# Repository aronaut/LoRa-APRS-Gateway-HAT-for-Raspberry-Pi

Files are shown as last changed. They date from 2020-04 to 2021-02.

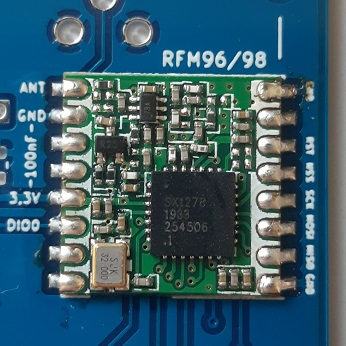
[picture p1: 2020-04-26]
Pictures/LoRa_APRS_3.jpg

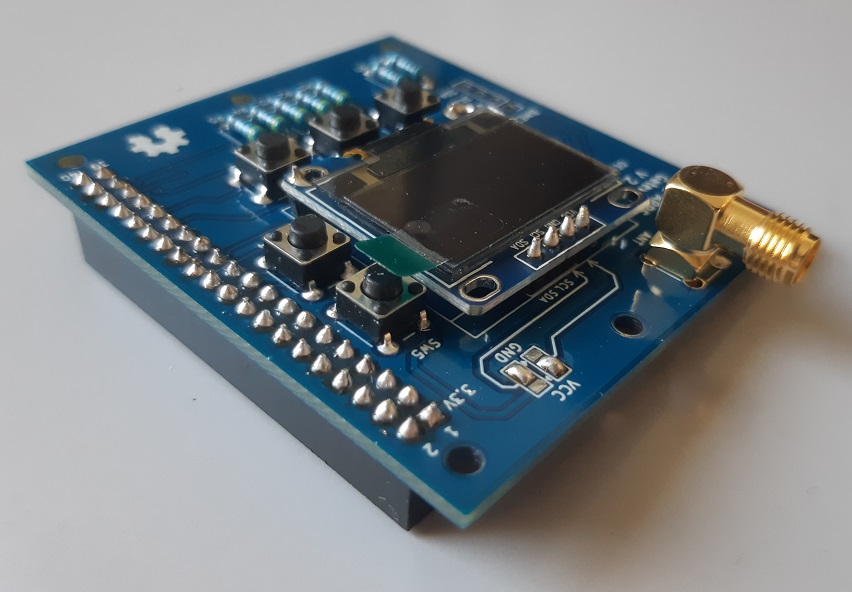
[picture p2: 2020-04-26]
Pictures/LoRa_APRS_7.jpg

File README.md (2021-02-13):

What is it?
-----------
With this LoRa APRS board you can build a LoRa APRS single channel Gateway.  
The Board is based on the development of https://www.lora-aprs.at/ and http://www.iot4pi.com/  
It works with a Raspberry Pi (2 Model B, 3 Model B an B+, Zero WH).  
Power is provided by Raspberry Pi.

What you find here
------------------
- KiCad Fils
- Gerber Files
- Manuals
- Pictures of the LoRa-APRS-Board

Info & Software
---------------
You find information and Software for the LoRa-APRS Gateway at  
https://www.aronaut.at/2019/11/lora-aprs-gateway-fur-raspberry-pi/  
https://www.lora-aprs.at/  
http://www.iot4pi.com/de/hardware/lora-gateway/  
https://github.com/tomelec/RPi-LoRa-KISS-TNC

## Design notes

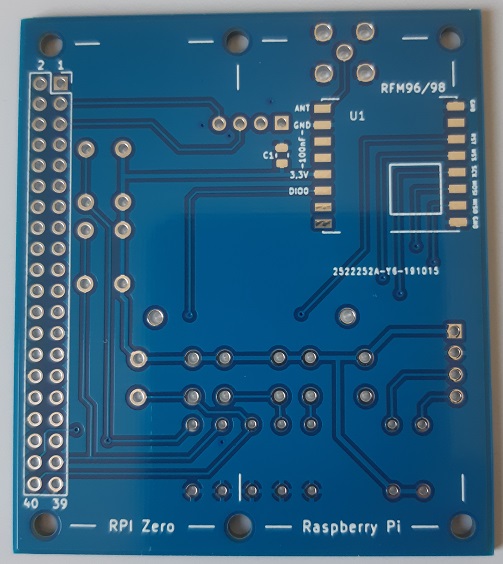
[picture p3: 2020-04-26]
Pictures/LoRa_APRS_2.jpg

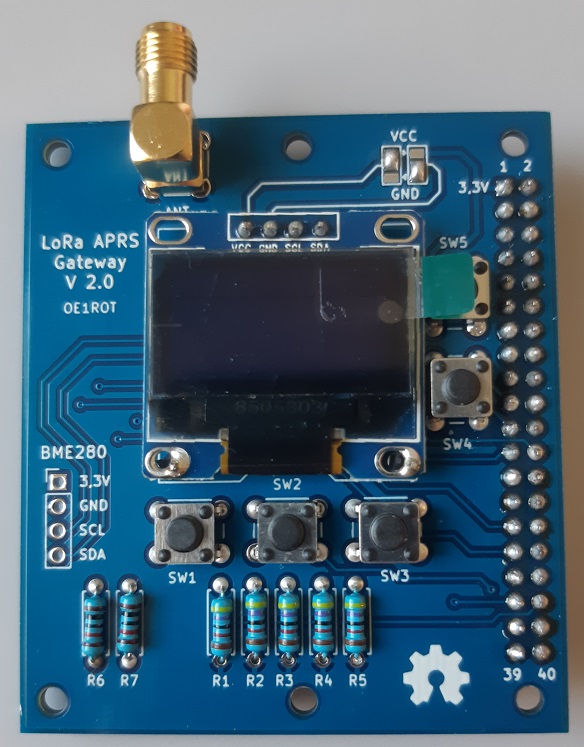
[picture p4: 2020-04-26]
Pictures/LoRa_APRS_5.jpg

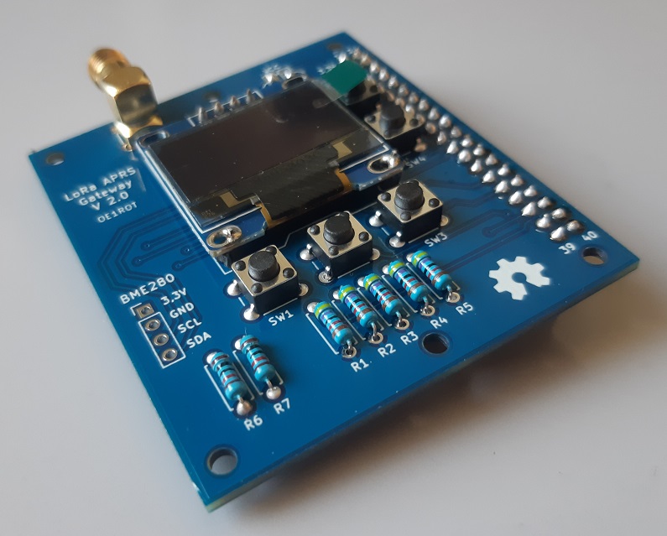
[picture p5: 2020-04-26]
Pictures/LoRa_APRS_6.jpg

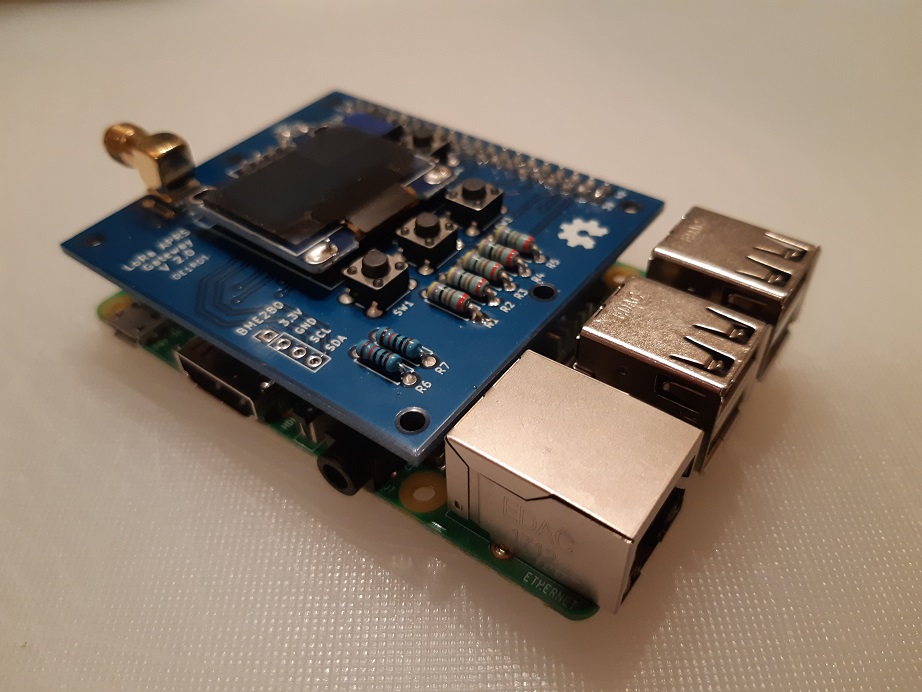
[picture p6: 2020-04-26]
Pictures/LoRa_APRS_8.jpg

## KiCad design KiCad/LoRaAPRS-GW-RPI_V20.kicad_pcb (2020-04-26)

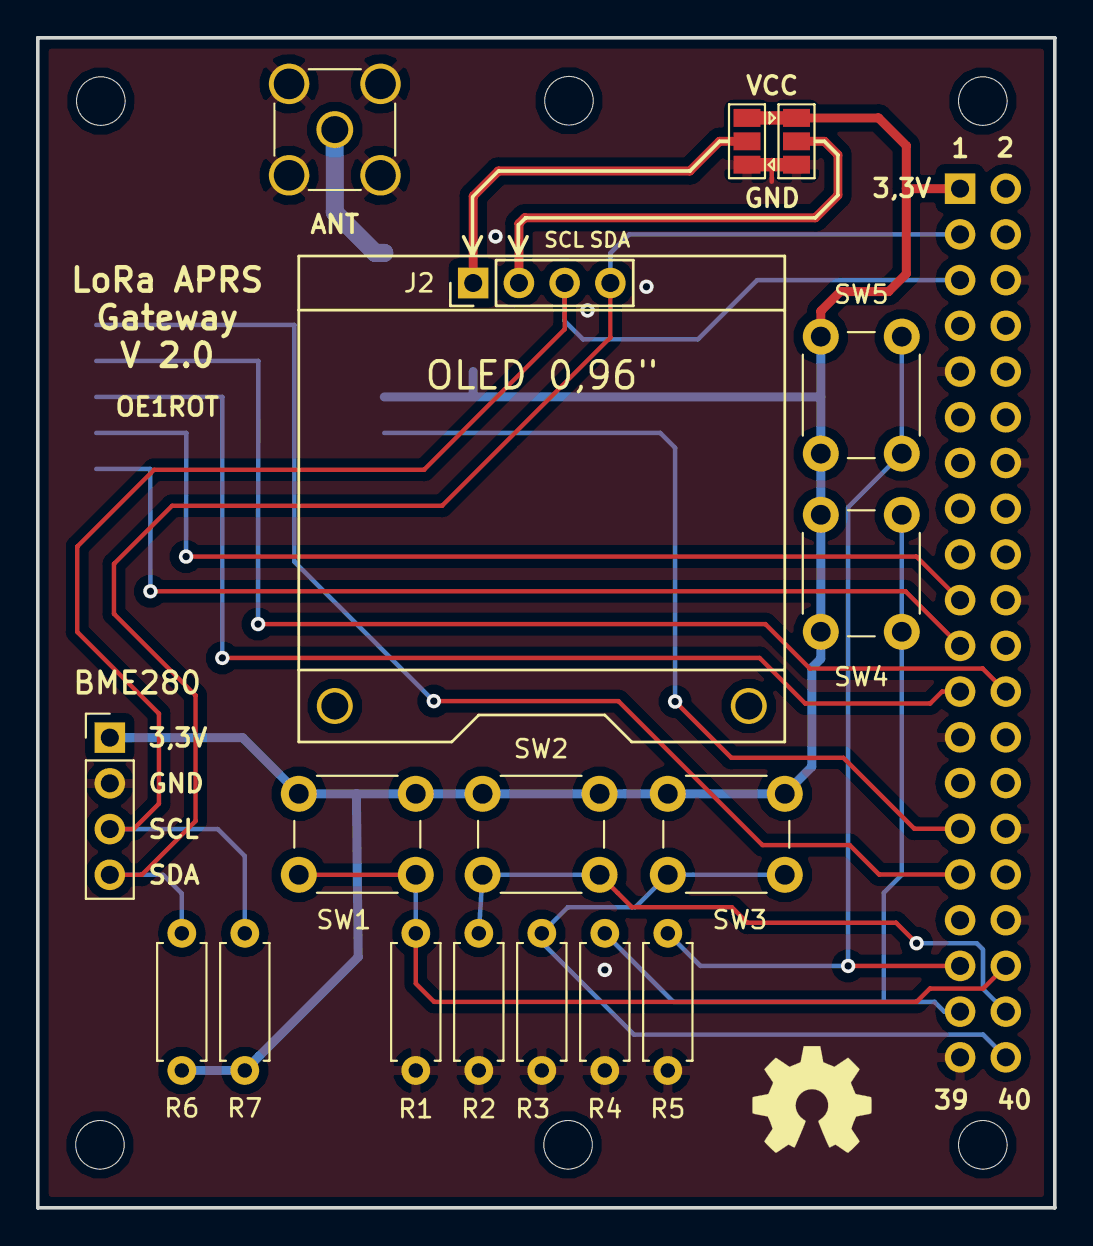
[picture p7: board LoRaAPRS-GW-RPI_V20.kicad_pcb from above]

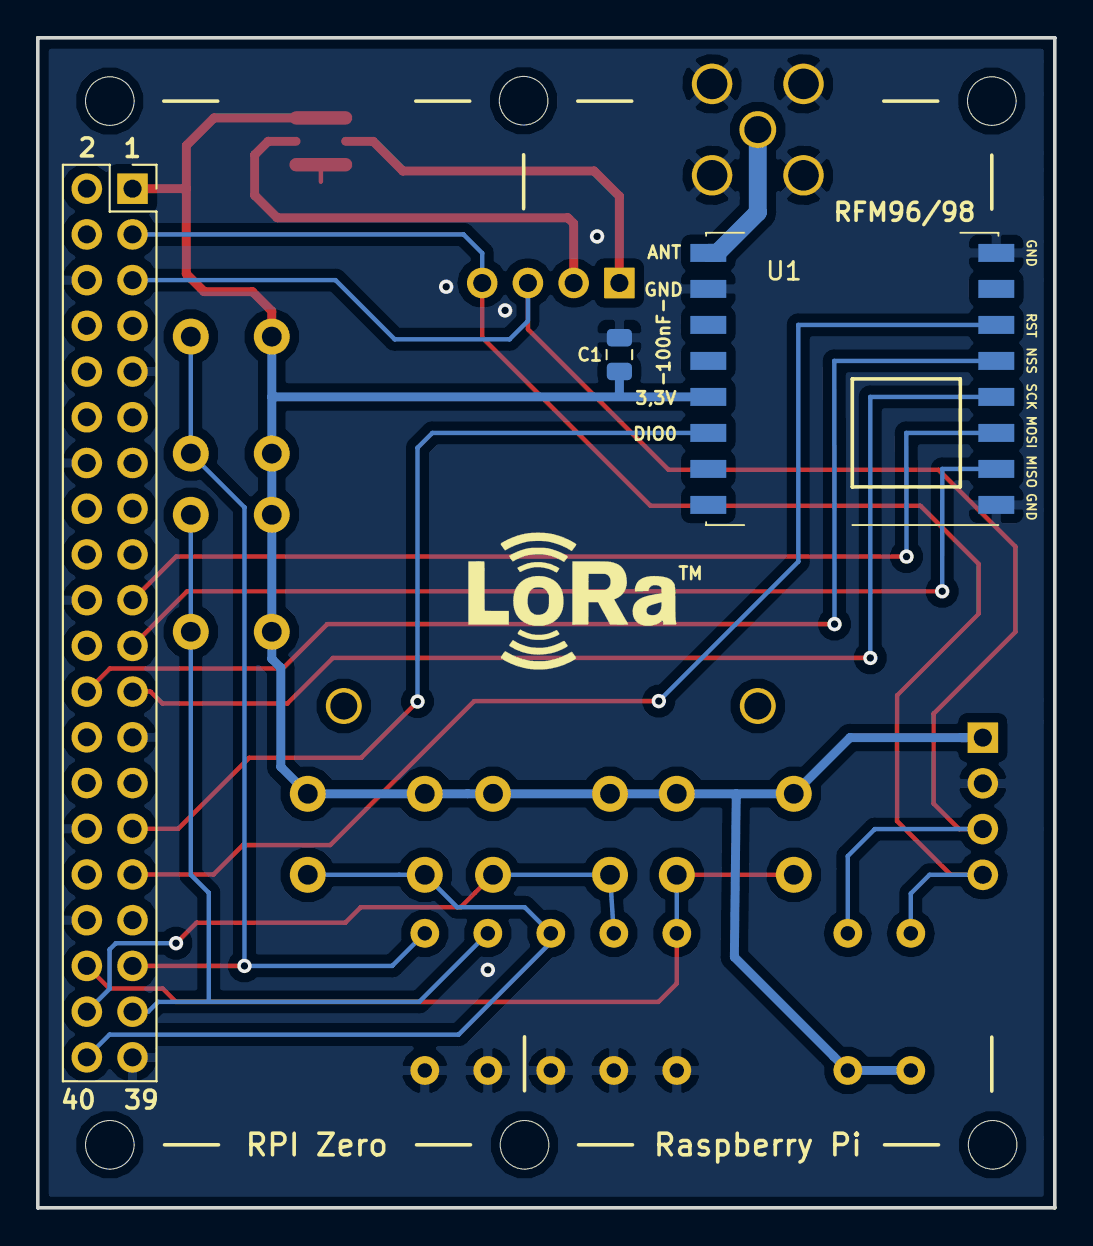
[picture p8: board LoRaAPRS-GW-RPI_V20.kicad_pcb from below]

Board: 2 copper layers, 56.5 x 65.0 mm, 20 parts (3 on the bottom side), 18 nets.

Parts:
AE1: Antenna_Shield; SMA_Amphenol_901-144_Vertical
C1: C; C_0805_2012Metric
J1: Raspberry PI Header; PinSocket_2x20_P2.54mm_Vertical
J2: Display; OLED_0,96_II
J3: BME280; PinHeader_1x04_P2.54mm_Vertical
JP1, JP2: SolderJumper_3_Open; SolderJumper-3_P1.3mm_Open_Pad1.0x1.5mm
R1, R2, R3, R4, R5: 47k; R_Axial_DIN0207_L6.3mm_D2.5mm_P7.62mm_Horizontal
R6, R7: 10k; R_Axial_DIN0207_L6.3mm_D2.5mm_P7.62mm_Horizontal
SW1, SW2, SW3, SW4, SW5: SW_Push; SW_PUSH_6mm_H5mm
U1: RFM96W-433S2; HOPERF_RFM9XW_SMD

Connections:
+3V3: C1.1, J1.1, J3.1, JP1.3, JP2.1, R6.1, R7.1, SW1.1, SW2.1, SW3.1, SW4.1, SW5.1, U1.13
D1: J2.1, JP1.2
D2: J2.2, JP2.2
DIO0: J1.29, U1.14
DOWN: J1.37, R4.1, SW4.2
GND: AE1.2, C1.2, J1.6, J1.9, J1.14, J1.20, J1.25, J1.30, J1.34, J1.39, J3.2, JP1.1, JP2.3, R1.2, R2.2, R3.2, R4.2, R5.2, U1.1, U1.8, U1.10
MISO: J1.21, U1.2
MOSI: J1.19, U1.3
NSS: J1.24, U1.5
unnamed: AE1.1, U1.9
Reset: J1.31, U1.6
SCK: J1.23, U1.4
SCL: J1.5, J2.3, J3.3, R7.2
SDA: J1.3, J2.4, J3.4, R6.2
T1: J1.36, R1.1, SW1.2
T2: J1.38, R2.1, SW2.2
T3: J1.40, R3.1, SW3.2
UP: J1.35, R5.1, SW5.2

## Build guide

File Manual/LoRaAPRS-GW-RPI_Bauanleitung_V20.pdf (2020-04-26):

# LoRa-APRS Gateway HAT V2.0 - Bauanleitung

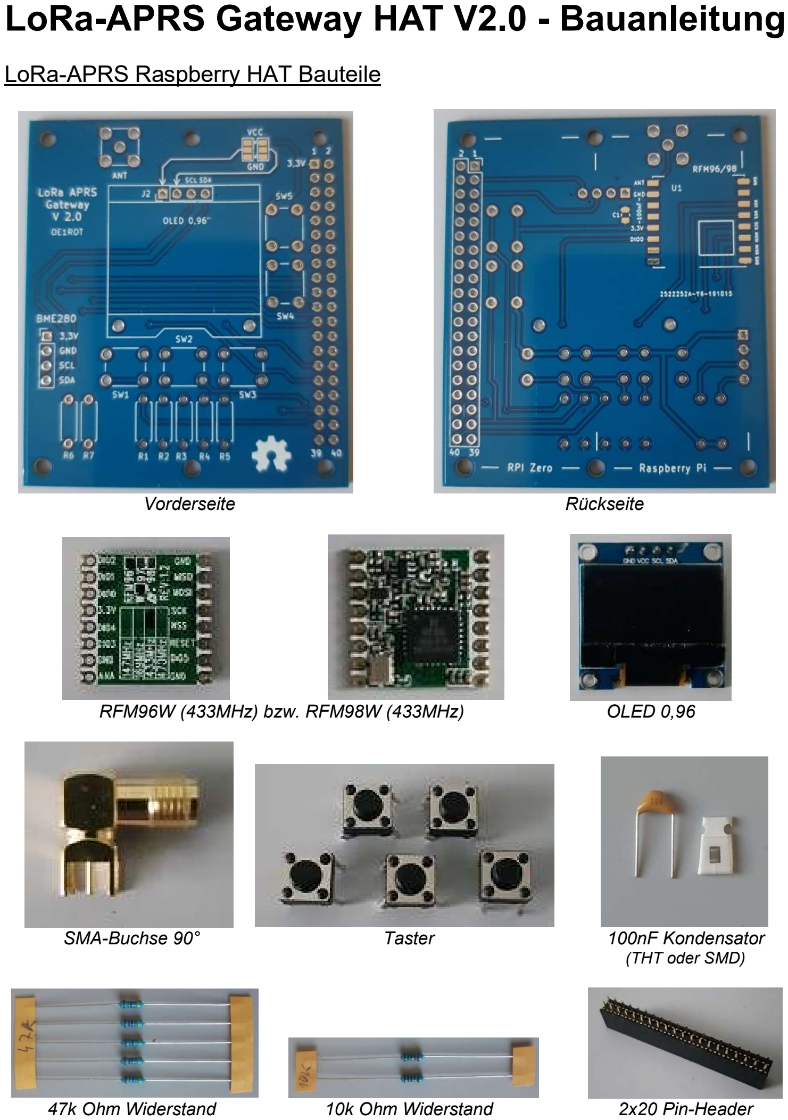
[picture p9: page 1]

LoRa-APRS Raspberry HAT Bauteile

Vorderseite | Rückseite
RFM96W (433MHz) bzw. RFM98W (433MHz) | OLED 0,96
SMA-Buchse 90° | Taster | 100nF Kondensator (THT oder SMD)
47k Ohm Widerstand | 10k Ohm Widerstand | 2x20 Pin-Header

### 1. Schritt – RFM96W / RFM98W

Als ersten Schritt wird der RFM96W/98W angelötet. Am einfachsten ist es das Lötzinn auf ein Pad (z.B. in einer Ecke) für den RFM96W/98W aufzutragen und danach den Baustein auszurichten. Ist der RFM-Chip ausgerichtet kann mit dem Lötkolben das Pad erwärmt werden und mit ein wenig Druck wird dieser fixiert. Dann werden die restlichen Pads an die Platine angelötet. Ein Fluxstift oder Lötpaste erleichtert das Aufbringen des Lötzinns.
Zur Kontrolle können die Lötpunkte mit einem Durchgangsprüfer kontrolliert werden.

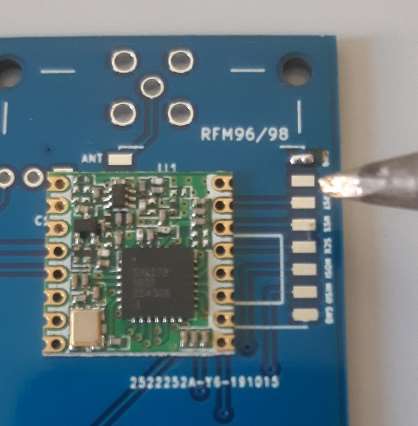
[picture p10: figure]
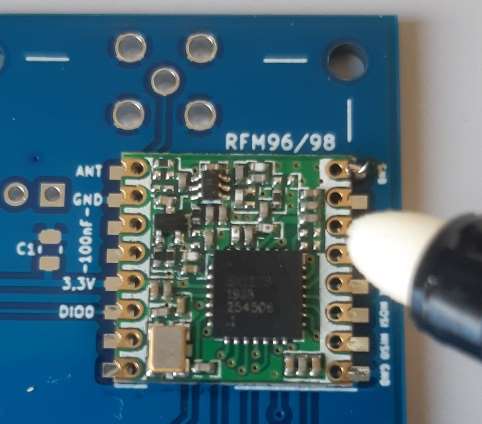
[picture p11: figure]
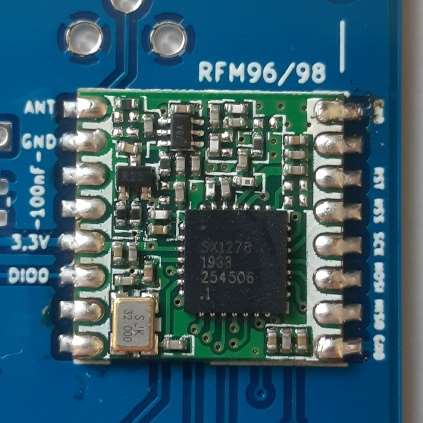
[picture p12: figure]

Lötzinn auftragen | RFM96W/98W ausrichten | RFM96W/98W anlöten
| Fluxstift

Passende Tranceiver Chip:
-) HopeRF: RFM96W / RFM98W (based on Semtech SX1279 / SX1278)

### 2. Schritt – Kondensator

Der 100nF Kondensator wird nun neben dem RFM96/98 angelötet.
Entweder man lötet einen THT Kondensator zwischen den RFM Pins GND-3,3V oder man lötet einen SMD Kondensator (Größe: 0805) an die vorhergesehenen Pads.

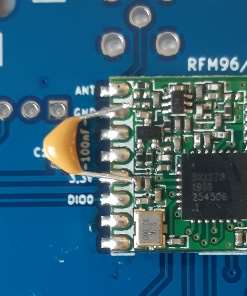
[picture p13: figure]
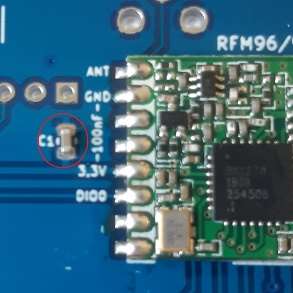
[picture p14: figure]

THT Kondensator | oder | SMD Kondensator

### 3. Schritt - Widerstände und Taster

Die Widerstände und die Taster werden nun an den vorhergesehenen Stellen eingelötet.

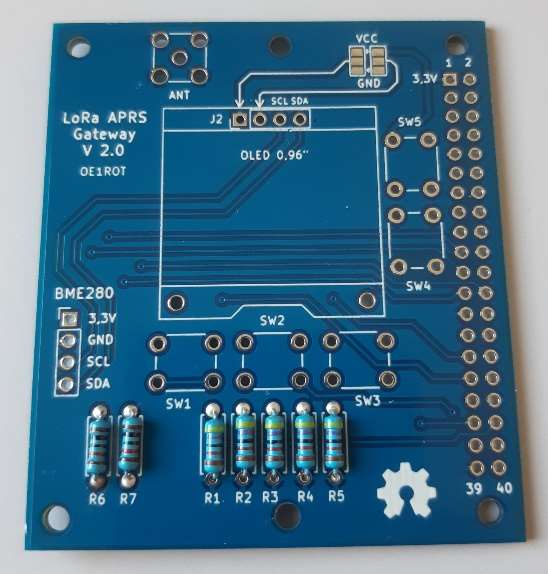
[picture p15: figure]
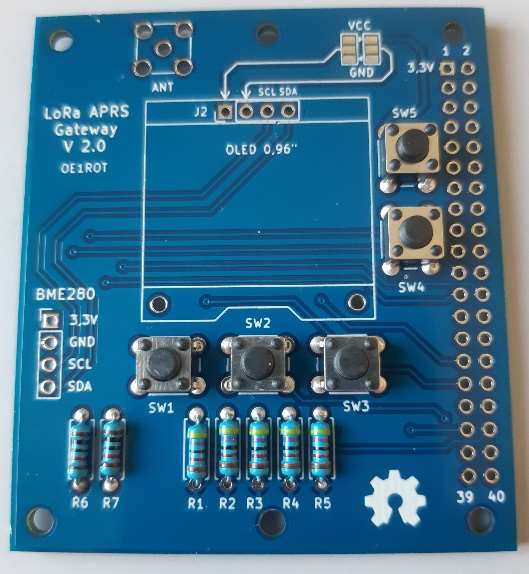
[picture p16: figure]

Widerstände einlöten | Taster einlöten
R6–R7=10k, R1–R5=47k

### 4. Schritt - Display (OLED 0,96)

Als nächstes wird das Display angelötet. Damit das Display stabil ist, können die Display-Montagelöcher mit der Platine verlötet werden.

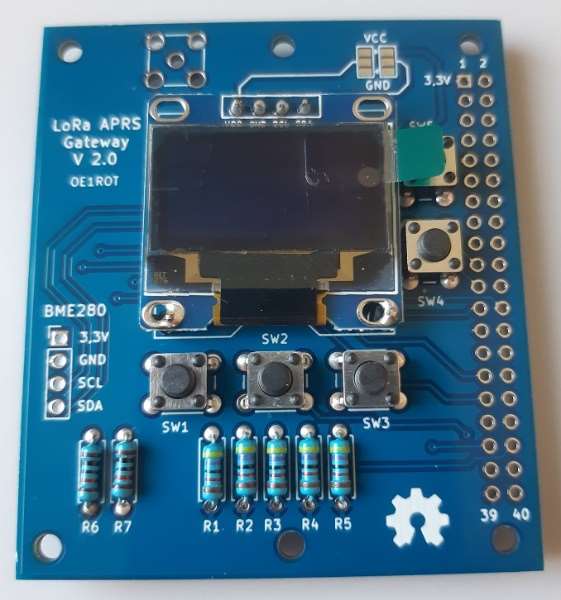
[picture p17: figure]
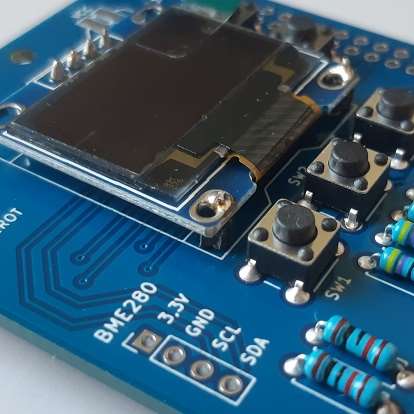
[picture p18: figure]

OLED 0,96 Display einlöten | Fixierung anbringen

### 5. Schritt - Display verbinden

Die verschiedenen Displayanschlüsse, GND-VCC-SCL-SDA bzw. VCC-GND-SCL-SDA, können mit dem Löt-Jumper eingestellt werden. Dazu werden die entsprechenden Lötpins mit Lötzinn verbunden. Oben: VCC=3,3V, Unten=GND

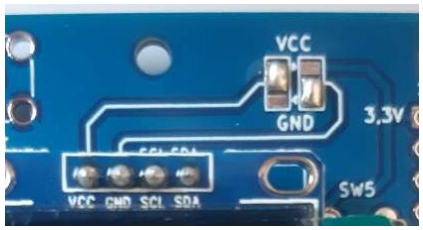
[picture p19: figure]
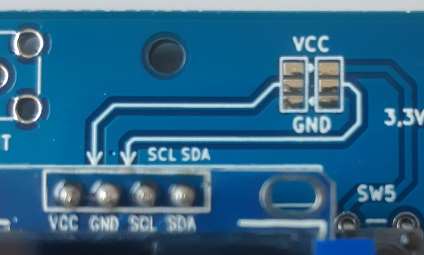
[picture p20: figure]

Löt-Jumper offen | Löt-Jumper verbunden

### 6. Schritt - SMA Buchse und Pin-Header

Als letzter Schritt wird die SMA Antennen Buchse und der 2x20 Pin-Header eingelötet.

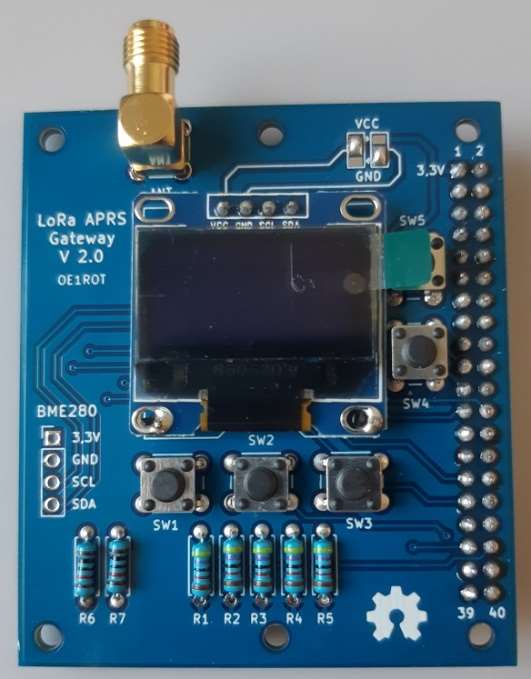
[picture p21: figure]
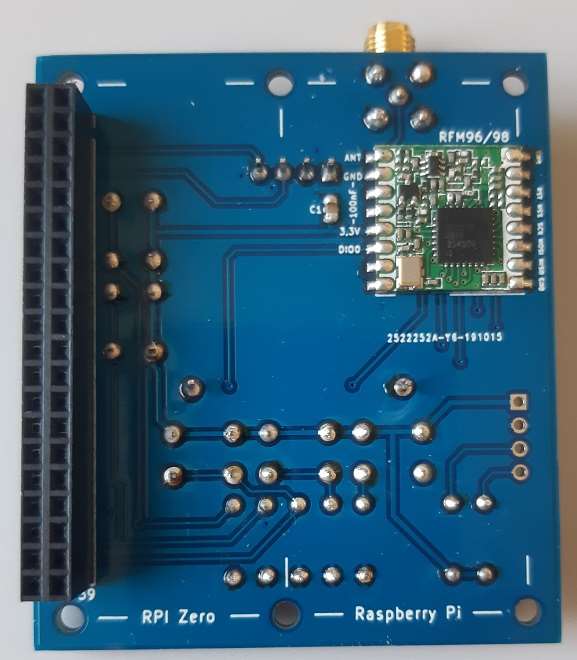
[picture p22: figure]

SMA-Buchse einlöten | Pin-Header einlöten

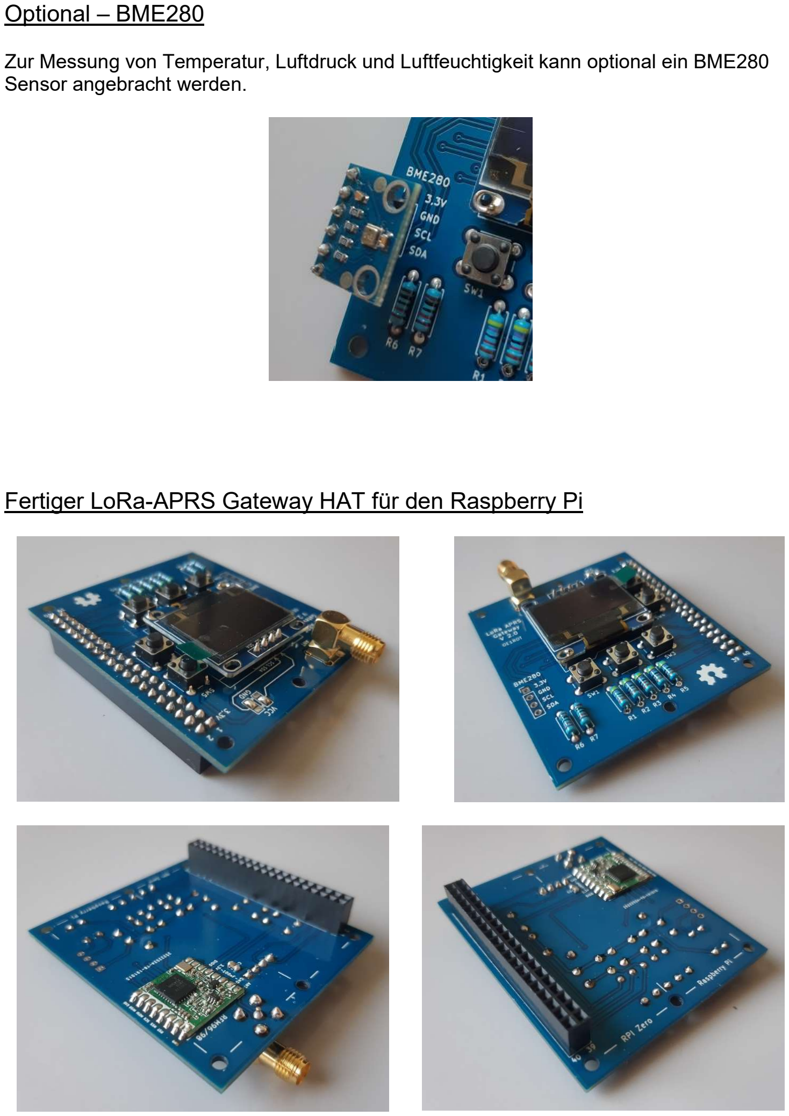
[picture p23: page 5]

Optional – BME280

Zur Messung von Temperatur, Luftdruck und Luftfeuchtigkeit kann optional ein BME280 Sensor angebracht werden.

Fertiger LoRa-APRS Gateway HAT für den Raspberry Pi

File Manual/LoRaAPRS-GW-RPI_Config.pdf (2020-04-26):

## LoRaAPRS-Gateway Konfiguration

-) Mit Win32 Disk Imager kannst du das IMG auf die MicroSD-Card schreiben.
-) Mit dem Programm PuTTY oder WinSCP kommst du mit SSH auf den Raspberry.
-) Mit dem Programm Advanced IP Scanner kannst du dein Netz nach der Raspi IP scannen.

Schreibe das Image auf die Micro SD-Card und stecke diese in den dafür vorgesehenen Platz auf dem Raspberry. Dann verbinde dich mit SSH auf den Raspberry und wechsle in das Verzeichnis „iot4pi“ um die Konfigurationsdatei APRS.conf zu editieren

User: pi / Password: LoRaAPRS

Mit dem Befehl cd /home/pi/iot4pi/ wechsle in das Verzeichnis „/home/pi/iot4pi/“
Mit dem Befehl sudo nano APRS.conf kannst du die Konfigurationsdatei ändern.

Notwendige Konfigurationen für dein Gateway sind
Calllsign, Passcode, Latitude, Longitude, IP-Adresse bzw. URL des APRS Servers und dessen Port

[SETUP]
#Configure this part with your call and APRS-IS passcode

APRS_IS_CALL:YourCall-SSID

#Edit this to be your passcode

APRS_IS_PASSCODE:12345

#Configure this part with your location, PHG (antenna description), and brief info

#APRS notation Latitude (DDMM.mmN or DDMM.mmS) and Longitude (DDMM.mmE or DDMM.mmW)

LATITUDE:4817.64N
LONGITUDE:01610.58E
PHG:PHG01000
INFO:IGate LoRa RX433.775 (no TX)

#You can change APRS_IS_HOST to a server geographically close to you. APRS_IS_HOST:igates.aprs.fi

APRS_IS_PORT:14580

Alle anderen Einstellungen sind voreingestellt und können beibehalten werden.

Optional – BME280
Verwendest du dein Gateway optional mit einem BME280 Sensor, dann musst du diesen auch in der Konfigurationsdatei APRS.conf frei schalten. (kommentieren / auskommentieren)
mit BME280 | ohne BME280
#BME280 if present set TRUE BME280:TRUE #BME280:False | #BME280 if present set TRUE #BME280:TRUE BME280:False

Mögliche APRS Server

APRS-Server via Internet | APRS-Server via Hamnet
igates.aprs.fi austria.aprs2.net germany.aprs2.net finland.aprs2.net ffl.aprs2.net euro.aprs2.net rotate.aprs2.net rotate.aprs.net | OE1XDS: 44.143.10.90 bzw. aprs.oe1.ampr.at OE2XZR: 44.143.40.90 bzw. aprs.oe2xzr.ampr.at OE7XGR: 44.143.168.96 bzw. aprs.oe7xgr.ampr.at OE2XWR: 44.143.43.90 OE2XGR: 44.143.41.29 OE5XUL: 44.143.105.158 DB0FFL: 44.149.16.136
Beispiel: APRS_IS_HOST:igates.aprs.fi APRS_IS_PORT:14580 | Beispiel: APRS_IS_HOST:44.143.10.90 APRS_IS_PORT:14580
